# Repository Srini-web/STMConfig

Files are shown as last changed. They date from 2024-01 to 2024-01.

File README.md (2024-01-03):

# STMConfig
## STM 32 Hardware Design and Custom Configuration using KiCad 7
The STM32 microcontroller model used here is the Blue Pill (STM32F103C8T6). It hosts the ARM Cortex M3 Microprocessor with a 32-bit RISC core operating at a 72 MHz frequency, and high-speed embedded memories. In this project, It has been interfaced with 
 + 1 USB (Micro-USB 2.0)
 + 1 UART line
 + 1 I2C2 line
 + Custom Oscillator
 + Regulator
   
#### Pin allocation and Power Configuration
There is a simple configuration performed therefore, although connected, the VBAT, and VDDA (Analog) are not actively used. To prevent power fluctuations and stabilize transitions, each Voltage source is provided with a decoupling capacitor and a bulk decoupling capacitor for all of them collectively. For the analog source, we need to provide an analog source linked to the collective VDD Supply. Since the analog voltage source is more sensitive, it is connected to a `ferrite bead ` of 120Ohm, 100MHz.

The `Reset` pin is connected to a pull-up circuit with a capacitor to prevent spurious resets. The `Boot0` pin used to enable or disable the upload and debugging of a program onto a board via the STMLINK is connected to a switch with a relatively high resistance.

##### Custom Oscillator
The `PD0` and `PD1` Pins are the oscillator i/o pins. For our custom oscillator, we have chosen the `SMD3225-4P` HSE(High-Speed External) Crystal Oscillator. Although the MCU has an in-built oscillator, an external oscillator not only provides better control and more precise clock speed but also enables the provision of a greater clock frequency. We have utilized it to provide greater frequency of `16MHz` using the oscillator.
Per the documentation, we connect two load capacitors whose value is determined by :-

```
CLoad = (Coscillator - CStray) * 2
CLoad = (10-5) *2 (stray capacitance ranges between 3 and 5 Farads)
CLoad = 10pF
```

##### USB
A Micro-USB (B) has been connected to the `PA11` and `PA12` pins which act as serial wire input and output pins. Specification is `STM: AN4879` . This circuitry is attached to a pull-up resistor circuit. 

##### Regulator
A regulator is required to filter the Input voltage provided through the `VBUS` input. This also serves as a power supply indicator using an LED in parallel. The specification is a linear resistor `AMS 3.3V` variant.

##### UART and I2C2
The UART and I2C2 pins are assigned to the `PB6`, `PB7`, and the `PB10`, `PB11` pins. The Pin assignment has been done using the STM32CubeIDE. After the assignment, the files are exported into KiCad. It is available in the `STM32F103C8T6_pinout.ioc` file. The clock circuitry generated also gives insights into the oscillator connection. A no connect `X` is attached to unused pins to avid ERC Violations.

stmcube

stmcubeclkckt

### Schematic

schematic

During ERC, A power source conflict is created at the analog voltage source, Due to 2 conflicting voltage sources which can be avoided using a power flag.

### Footprint Assignment

Footprint assignment is done to ensure each component specification is done for PCB design and Manufacturing

footprint

### Planning (Layout)
It is a 2 layer board  into which the schematic footprints are imported and components are placed guided by the rat's nest links. Edge planning and mount holes are also added. Component labeling and notes are created using silkscreen. This is where the mount holes are also added, edge cuts are made defining board edges and the 3D model of the USB is appended to the footprint using the `629105150521 (rev1).stp` CAD file downloaded from the component site.

placement

### Routing 
+ Path routing is essential and dependent on the efficiency of Planning. Two tracks have been used. Namely the 0.3 mm and 0.5 mm tracks. The smaller tracks are mostly used for signal routing and the larger/ broader track is used for power routing and ground vias.
+ Certain connects are connected by a power puddle during power routing. If this is not done properly, This may cause a copper imbalance leading to Tombstoning.

##### Signal Routing
SignalRouting

##### Power Routing
PowerRouting

##### 3D view after P&R

3DModelF

3DModelB

### Manufacturing
Following DRC clearance, to prepare the manufacturing model, the material list is generated from the schematic. After specifying and generating the drill hole list, The Gerber files are generated. All of these are available in the `Manufacturing` folder.

Gerber1

Gerber2

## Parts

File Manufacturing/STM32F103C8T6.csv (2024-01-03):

Source: | D:\KiCad\STM32F103C8T6\STM32F103C8T6.kicad_sch
Date: | 02-01-2024 09:34:44
Tool: | Eeschema 7.0.9
Generator: | C:\Program Files\KiCad\7.0\bin\scripting\plugins/bom_csv_grouped_by_value_with_fp.py
Component Count: | 32
Ref | Qnty | Value | Cmp name | Footprint | Description | Vendor | DNP
C1, C2, C3, C4, C9 | 5 | 100n | C | Capacitor_SMD:C_0402_1005Metric | Unpolarized capacitor
C5 | 1 | 10u | C | Capacitor_SMD:C_0603_1608Metric | Unpolarized capacitor
C6 | 1 | 10n | C | Capacitor_SMD:C_0402_1005Metric | Unpolarized capacitor
C7, C8 | 2 | 1u | C | Capacitor_SMD:C_0402_1005Metric | Unpolarized capacitor
C10, C11 | 2 | 10p | C | Capacitor_SMD:C_0402_1005Metric | Unpolarized capacitor
C12, C13 | 2 | 22u | C | Capacitor_SMD:C_0805_2012Metric | Unpolarized capacitor
D1 | 1 | RED | LED | LED_SMD:LED_0603_1608Metric | Light emitting diode
FB1 | 1 | 120R | FerriteBead | Inductor_SMD:L_0603_1608Metric | Ferrite bead
H1, H2, H3, H4 | 4 | MountingHole | MountingHole | MountingHole:MountingHole_2.2mm_M2 | Mounting Hole without connection
J1 | 1 | USB_B_Micro | USB_B_Micro | Connector_USB:USB_Micro-B_Wuerth_629105150521 | USB Micro Type B connector
J2, J3, J4 | 3 | Conn_01x04_Pin | Conn_01x04_Pin | Connector_PinHeader_2.54mm:PinHeader_1x04_P2.54mm_Vertical | Generic connector, single row, 01x04, script generated
R1 | 1 | 10k | R | Resistor_SMD:R_0402_1005Metric | Resistor
R2, R3, R4, R5 | 4 | 1k5 | R | Resistor_SMD:R_0402_1005Metric | Resistor
SW1 | 1 | SW_SPDT | SW_SPDT | Button_Switch_SMD:SW_SPDT_PCM12 | Switch, single pole double throw
U1 | 1 | STM32F103C8T6 | STM32F103C8Tx | Package_QFP:LQFP-48_7x7mm_P0.5mm | STMicroelectronics Arm Cortex-M3 MCU, 64KB flash, 20KB RAM, 72 MHz, 2.0-3.6V, 37 GPIO, LQFP48
U2 | 1 | AMS1117-3.3 | AMS1117-3.3 | Package_TO_SOT_SMD:SOT-223-3_TabPin2 | 1A Low Dropout regulator, positive, 3.3V fixed output, SOT-223
Y1 | 1 | 16MHz | Crystal_GND24 | Crystal:Crystal_SMD_3225-4Pin_3.2x2.5mm | Four pin crystal, GND on pins 2 and 4

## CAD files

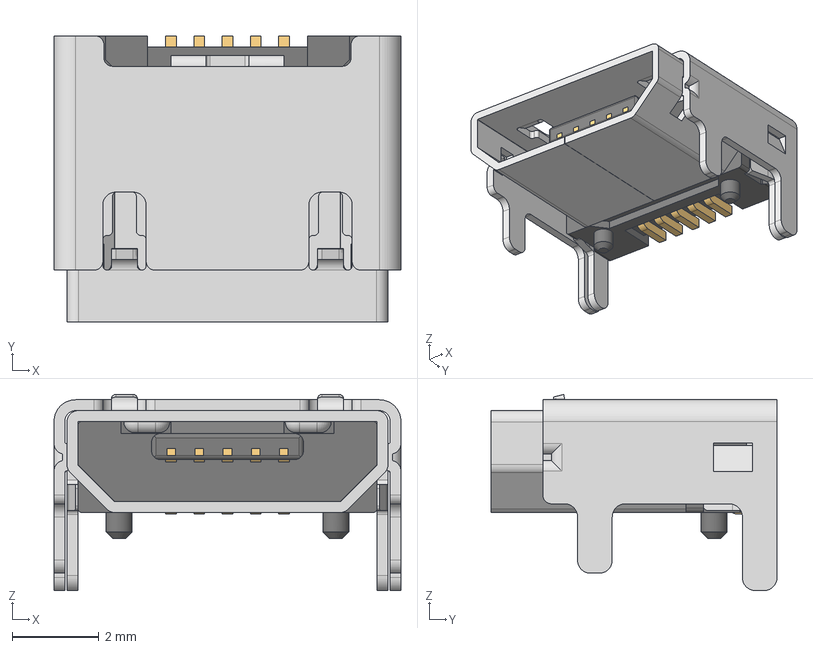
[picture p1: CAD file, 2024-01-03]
629105150521 (rev1).stp
8.00 x 6.60 x 4.52 mm
629105150521_Housing
629105150521_Pin1 x 4
629105150521_Pin2
629105150521_Shielding2
629105150521_Shielding

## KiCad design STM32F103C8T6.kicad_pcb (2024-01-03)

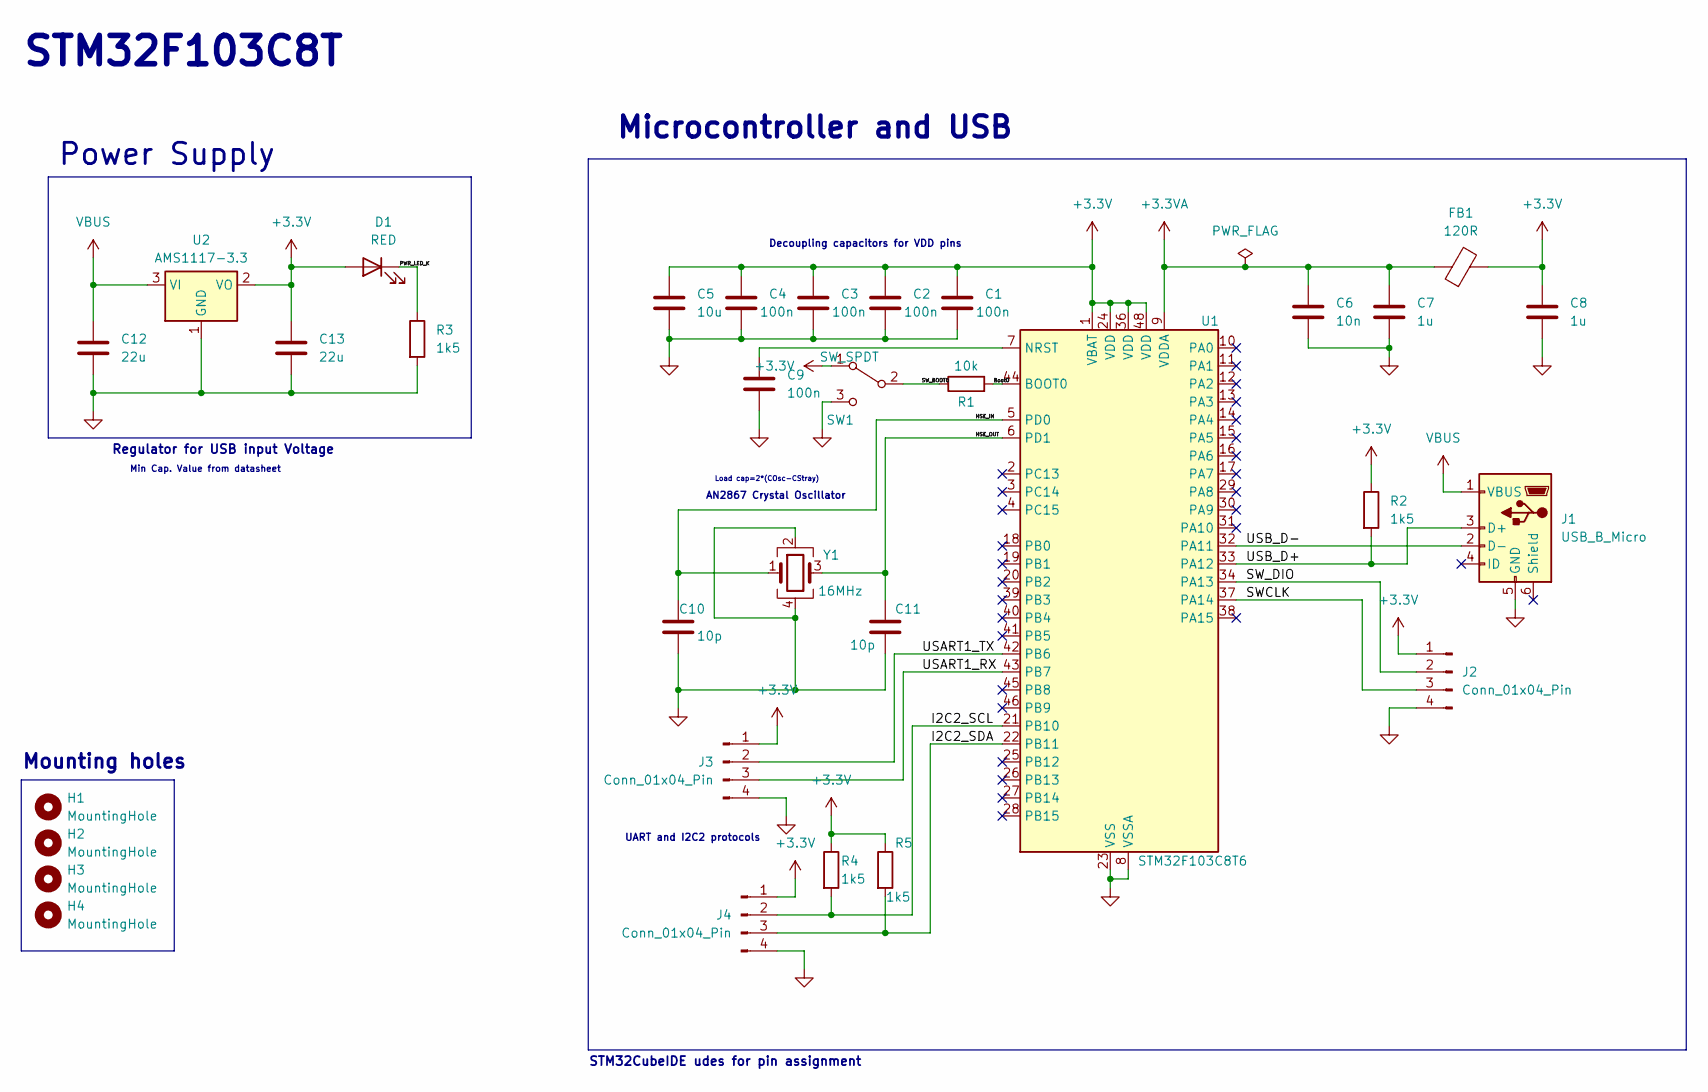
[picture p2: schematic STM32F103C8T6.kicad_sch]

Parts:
C1, C2, C3, C4, C9: 100n; C_0402_1005Metric
C5: 10u; C_0603_1608Metric
C6: 10n; C_0402_1005Metric
C7, C8: 1u; C_0402_1005Metric
C10, C11: 10p; C_0402_1005Metric
C12, C13: 22u; C_0805_2012Metric
D1: RED; LED_0603_1608Metric
FB1: 120R; L_0603_1608Metric
H1, H2, H3, H4: MountingHole; MountingHole_2.2mm_M2
J1: USB_B_Micro; USB_Micro-B_Wuerth_629105150521
J2, J3, J4: Conn_01x04_Pin; PinHeader_1x04_P2.54mm_Vertical
R1: 10k; R_0402_1005Metric
R2, R3, R4, R5: 1k5; R_0402_1005Metric
SW1: SW_SPDT; SW_SPDT_PCM12
U1: STM32F103C8T6; LQFP-48_7x7mm_P0.5mm
U2: AMS1117-3.3; SOT-223-3_TabPin2
Y1: 16MHz; Crystal_SMD_3225-4Pin_3.2x2.5mm

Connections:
+3.3V: C1.1, C2.1, C3.1, C4.1, C5.1, C8.1, C13.1, D1.2 (A), FB1.2, J2.1, J3.1, J4.1, R2.1, R4.1, R5.1, SW1.1 (A), U1.1 (VBAT), U1.24 (VDD), U1.36 (VDD), U1.48 (VDD), U2.2 (VO)
+3.3VA: C6.1, C7.1, FB1.1, U1.9 (VDDA)
/Boot0: R1.2, U1.44 (BOOT0)
/HSE_IN: C10.1, U1.5 (PD0), Y1.1
/HSE_OUT: C11.1, U1.6 (PD1), Y1.3
/I2C2_SCL: J4.2, R4.2, U1.21 (PB10)
/I2C2_SDA: J4.3, R5.2, U1.22 (PB11)
/PWR_LED_K: D1.1 (K), R3.1
/SWCLK: J2.3, U1.37 (PA14)
/SW_BOOT0: R1.1, SW1.2 (B)
/SW_DIO: J2.2, U1.34 (PA13)
/USART1_RX: J3.3, U1.43 (PB7)
/USART1_TX: J3.2, U1.42 (PB6)
/USB_D+: J1.3 (D+), R2.2, U1.33 (PA12)
/USB_D-: J1.2 (D-), U1.32 (PA11)
GND: C1.2, C2.2, C3.2, C4.2, C5.2, C6.2, C7.2, C8.2, C9.2, C10.2, C11.2, C12.2, C13.2, J1.5 (GND), J2.4, J3.4, J4.4, R3.2, SW1.3 (C), U1.8 (VSSA), U1.23 (VSS), U1.35 (VSS), U1.47 (VSS), U2.1 (GND), Y1.2, Y1.4
unnamed: C9.1, U1.7 (NRST)
VBUS: C12.1, J1.1 (VBUS), U2.3 (VI)

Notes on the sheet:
Decoupling capacitors for VDD pins
STM32F103C8T
Power Supply
AN2867 Crystal Oscillator
UART and I2C2 protocols
Regulator for USB input Voltage
Load cap=2*(COsc-CStray)
Mounting holes
Microcontroller and USB
STM32CubeIDE udes for pin assignment
Min Cap. Value from datasheet

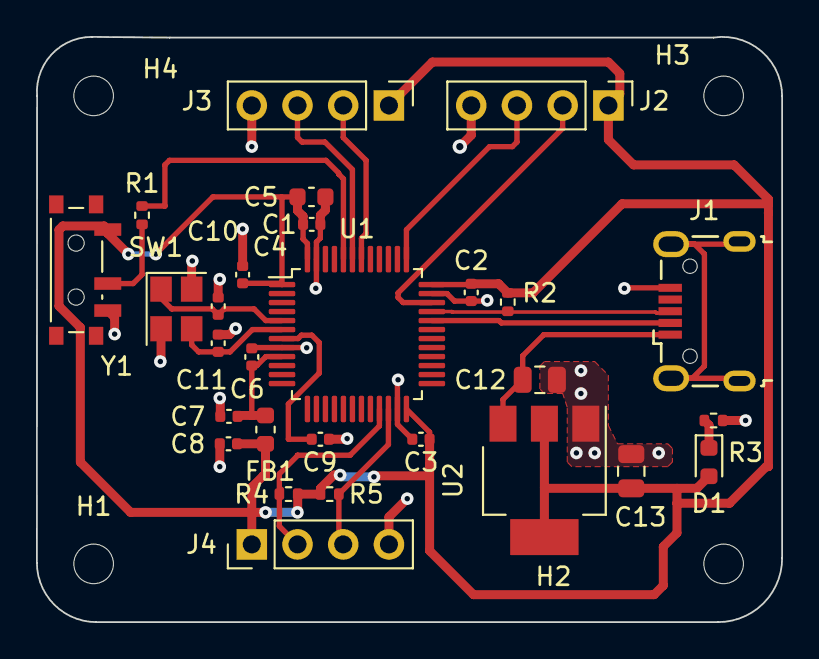
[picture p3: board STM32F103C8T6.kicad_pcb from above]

Board: 2 copper layers, 41.4 x 32.5 mm, 32 parts (0 on the bottom side), 18 nets.

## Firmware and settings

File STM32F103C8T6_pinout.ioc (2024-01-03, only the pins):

Mcu.UserName=STM32F103C8Tx
PA11.Signal=USB_DM
PA12.Signal=USB_DP
PA13.Signal=SYS_JTMS-SWDIO
PA14.Signal=SYS_JTCK-SWCLK
PB10.Signal=I2C2_SCL
PB11.Signal=I2C2_SDA
PB6.Signal=USART1_TX
PB7.Signal=USART1_RX
PD0-OSC_IN.Signal=RCC_OSC_IN
PD1-OSC_OUT.Signal=RCC_OSC_OUT
